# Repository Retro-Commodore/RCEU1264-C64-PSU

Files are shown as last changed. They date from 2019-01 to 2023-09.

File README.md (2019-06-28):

# C64-PSU
A C64/C128/Vic20/Plus4 PSU
This is a full replacement PSU with modern electronics that won't kill your computer when it gets bad.. the original PSU's short input to output, when they break, feeding approx 10v.
While it is possible to use wall warts, this design is created to be easy to diy, somewhat pretty and closer to the old designs with off the shelf items.

Greetz to Trap/Bonzai for being the source of inspiration to create this.

The PSU can be used for the C64 even with i.e. 1541 Ultimate and Vic20, and it's powerful enough to feed the C128 and/or 17xx REU.

All parts can be bought at [tme.eu](https://www.tme.eu/), and the pcb has been designed with parts from there.
A few parts like the DIN connector and fuse socket can be aqcuired from ebay where they're much cheaper.

*If you are a reseller, and use my designs, though the projects are open source, I'd like to ask you to donate a small amount of money, to cancer research for each sold device.*

The Mean Well IRM-20-5 is Short circuit / Overload / Over voltage protected (pdf's from Mean Well are in the documentation folder).

**The trafo is a 230v trafo, so countries that use 115v will need a different trafo.**

If you want to add an on/off switch, the easiest might be a switch on the 230v cable, or a round one, the round one is easiest to make holes to -by drilling-, rather than cutting a square one. But that is entirely up to you :-) .

The gerber files which is the zip file found in [hardware/eagle](https://github.com/Retro-Commodore/C64-PSU/tree/master/Hardware/Eagle Gerber) can be uploaded as is to PCB manufacturing companies like [JLCPCB](http://jlcpcb.com).

The PCB is created with Eagle which has a limiting size of 100x100mm (or is it 100x80mm?). And the PCB is within this size.
The newest version of KiCAD should be able to import the eagle files, in case you prefer this. 

**TODO**
* Add possibility to use PTC (one has to be sourced first), if you read this and know of one already please don't hesitate to add a ticket with the info. You'll providing the community a service :-)

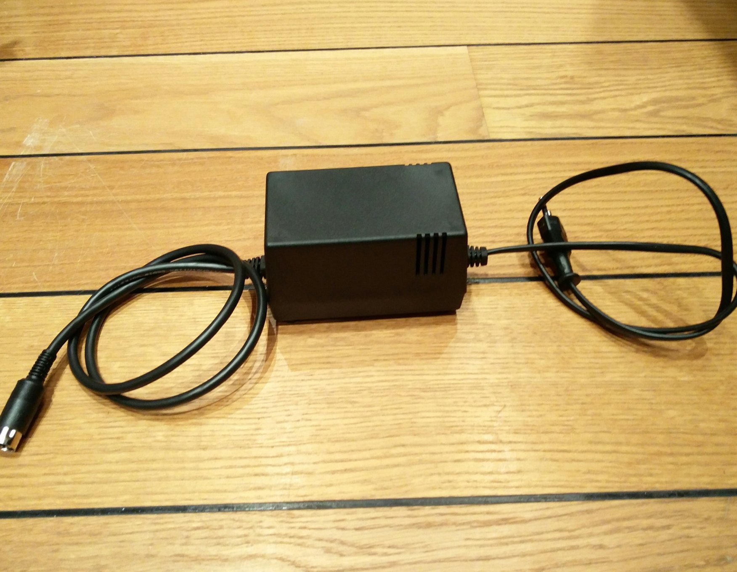
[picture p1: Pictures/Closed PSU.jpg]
PSU


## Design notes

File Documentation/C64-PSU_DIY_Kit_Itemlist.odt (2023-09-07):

Some of the major components needed for the PSU.

9v AC trafo

https://www.tme.eu/en/details/tez10_d_9v/pcb-transformers/breve-tufvassons/tez10d2309v/

4A (who can ever get enough?) with this you can adapt the PSU to work with a C128

5v DC 4A

https://www.tme.eu/en/details/irm-20-5/built-in-power-supplies/mean-well/

Enclosure:

https://www.tme.eu/en/details/z16-abs/power-supplies-enclosures/kradex/z16-abs/

4Wire cable: the last one is preferable

https://www.tme.eu/en/details/cf890.05.04/cables-for-power-chains-unshielded/igus/

https://www.tme.eu/en/details/therm120_4g0.5/multicore-cables-unshielded/helukabel/24004/

The PCB, order at i.e. jlcpcb.com and upload the gerber file (zip file).

Also needed, which can be gotten cheaply from eBay.

Fuse socket

500mA T fuse

7 pin DIN

230v power cable (C7 to Euro)

Optional:

LED

Resistor 330 ohm, might be a good choice but needs calculating depending on color.

A 4A PSU can be created for around £18

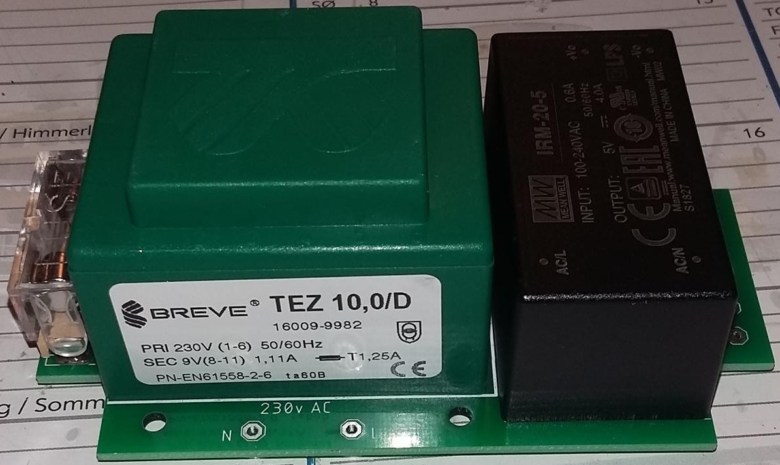
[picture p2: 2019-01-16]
Pictures/pic.jpg

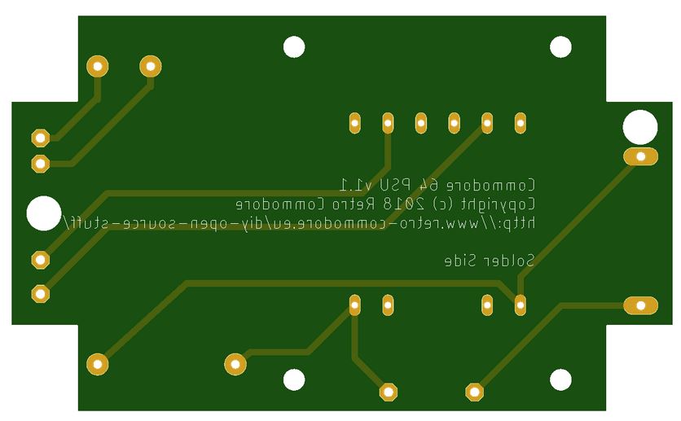
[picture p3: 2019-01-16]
Pictures/bottom.jpg

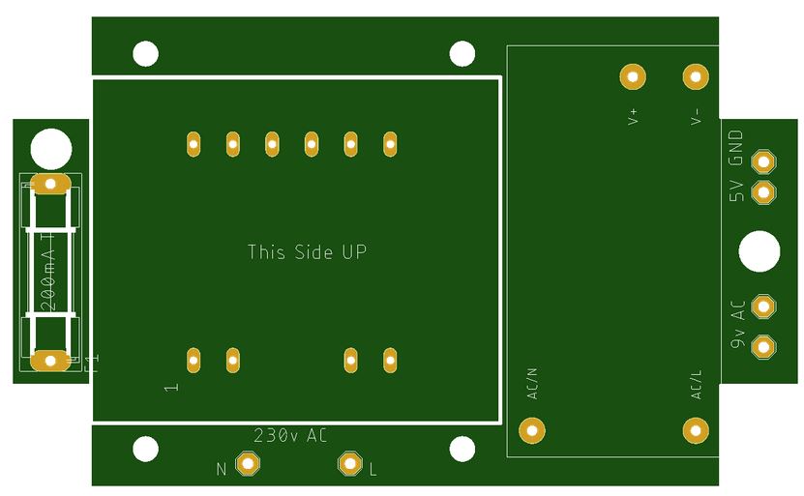
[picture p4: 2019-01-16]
Pictures/top.jpg

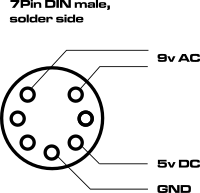
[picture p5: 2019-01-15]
Graphics/DIN.png

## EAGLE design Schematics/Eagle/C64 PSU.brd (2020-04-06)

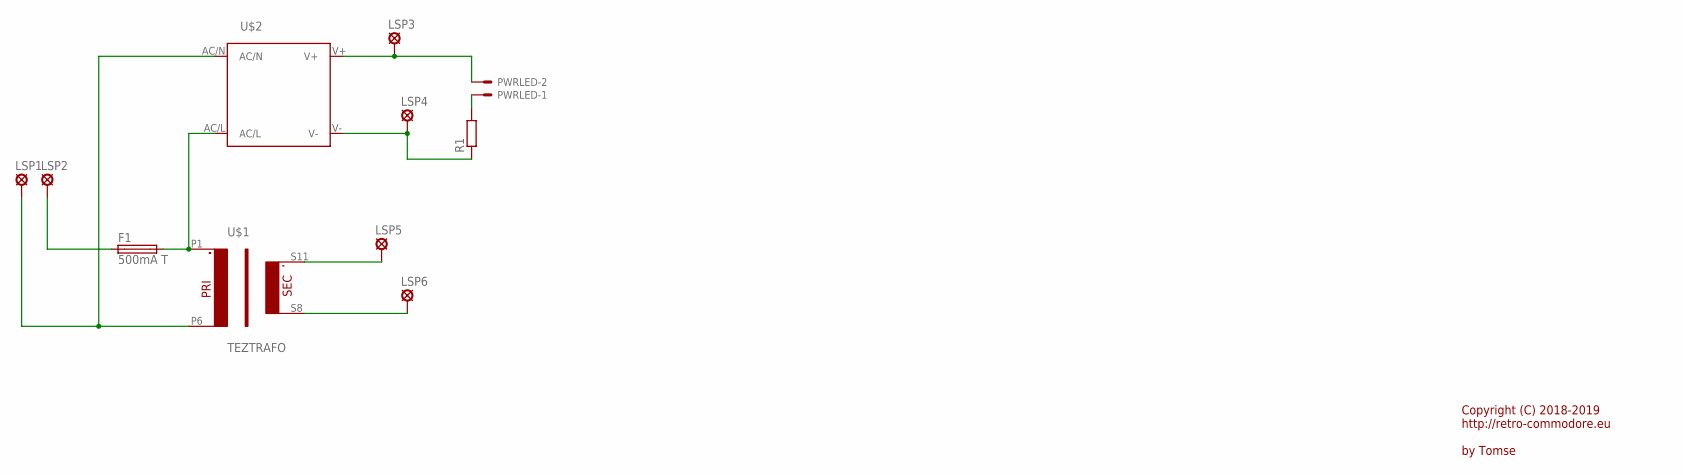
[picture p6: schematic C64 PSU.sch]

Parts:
F1: 500mA T; SH22,5
LSP1, LSP2, LSP3, LSP4, LSP5, LSP6: SE14
PWRLED: 22-23-2021
R1: R-EU_0207/10; 0207/10
U$1: TEZTRAFO; TEZ10/D230/9V
U$2: IRM_15/20IRM_15/20; IRM_15/20

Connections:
unnamed: F1.2, U$1.P1, U$2.AC/L
unnamed: LSP1.MP, U$1.P6, U$2.AC/N
unnamed: F1.1, LSP2.MP
unnamed: LSP6.MP, U$1.S8
unnamed: LSP5.MP, U$1.S11
unnamed: LSP4.MP, R1.1, U$2.V-
unnamed: LSP3.MP, PWRLED.2, U$2.V+
unnamed: PWRLED.1, R1.2

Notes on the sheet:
Copyright (C) 2018-2019 http://retro-commodore.eu by Tomse

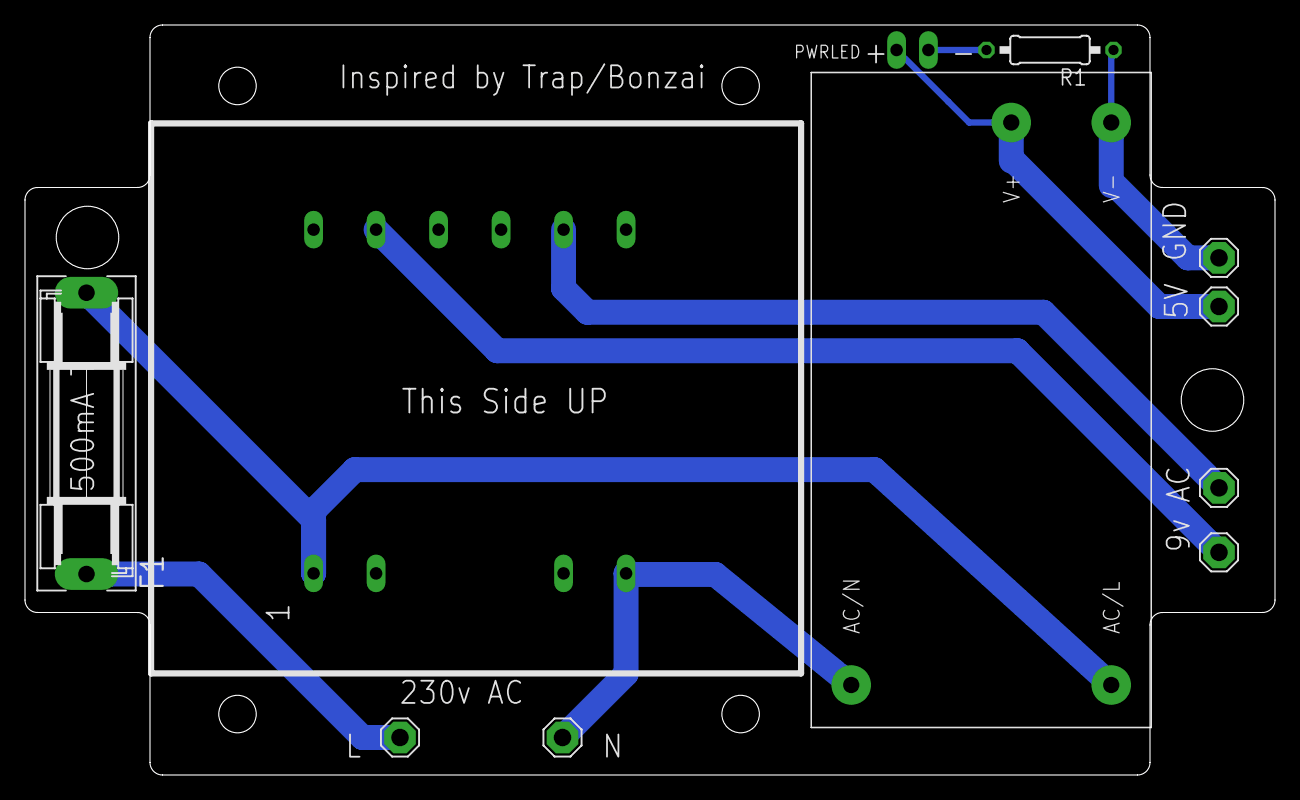
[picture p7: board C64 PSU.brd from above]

Board: 2 copper layers, 100.0 x 60.0 mm, 11 parts (0 on the bottom side), 8 nets.

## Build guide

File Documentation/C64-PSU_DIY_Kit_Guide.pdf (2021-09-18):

# C64 / Vic20 / C128* / plus/4*

# PSU DIY Kit

# from

# http://retro-commodore.eu

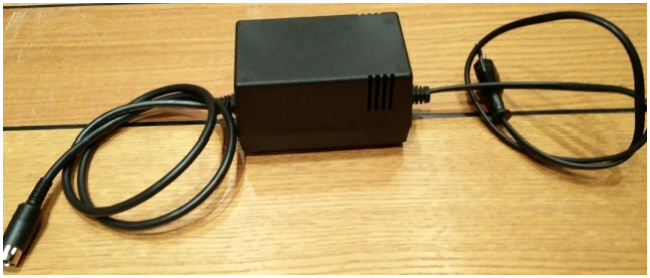
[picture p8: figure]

Table of Contents

Copyright © 2018-2021 http://retro-commodore.eu

### Introduction:

This is the http://retro-commodore.eu version of a C64 PSU.
The project can be found and downloaded for free at https://github.com/Retro-Commodore/ (https://github.com/Retro-Commodore/)
The PSU Works as is with C64 and Vic20, but can be used for C128 and plus/4 as well, with the square DIN connector instead.

### Warning:

Warning! as the psu works with 230v you shouldn’t be soldering this project unless you know what you’re doing. No one but yourself are responsible if the PSU catches fire due to bad/cold soldering joints, so be warned.

### Solder guide:

If you haven’t read the warning, please do so before continuing.

DIN connector

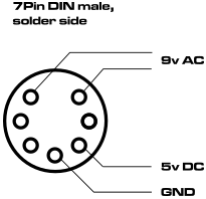
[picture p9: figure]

Copyright © 2018-2021 http://retro-commodore.eu

Print Circuit Board (PCB):
The PCB can mistakenly be solder from both sides, so make sure that you attach the components on top of the PCB hat says ”This Side UP”.

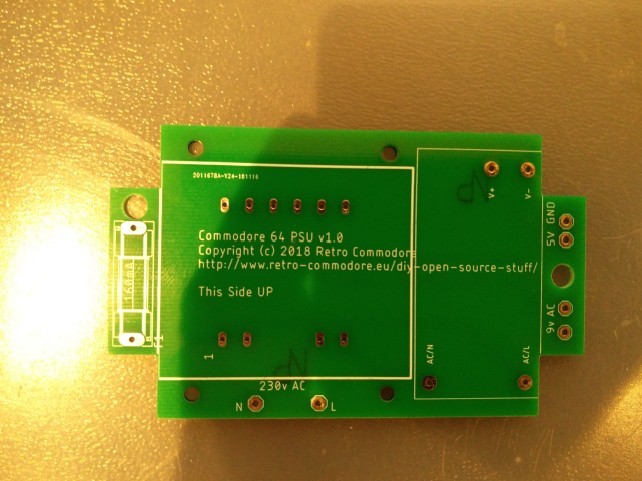
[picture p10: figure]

Copyright © 2018-2021 http://retro-commodore.eu

Trafo:
Insert the trafo on top of the pcb, with the side thats written ”This side up”. The trafo is key coded so you can only insert it one way.
Solder it to the PCB.

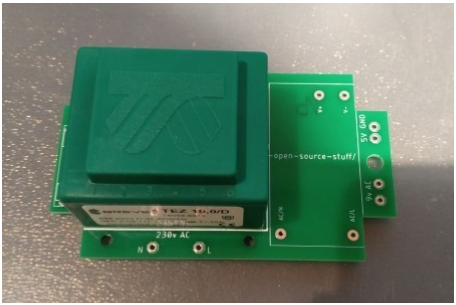
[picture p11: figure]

The trafo generates the 9v AC needed for the SID, if you measure the output you might get around 10v AC, thats fine. The voltage will drop once connected and powered on.

Copyright © 2018-2021 http://retro-commodore.eu

5v supply:
After soldering the trafo, you can now add the 5v psu to the pcb.

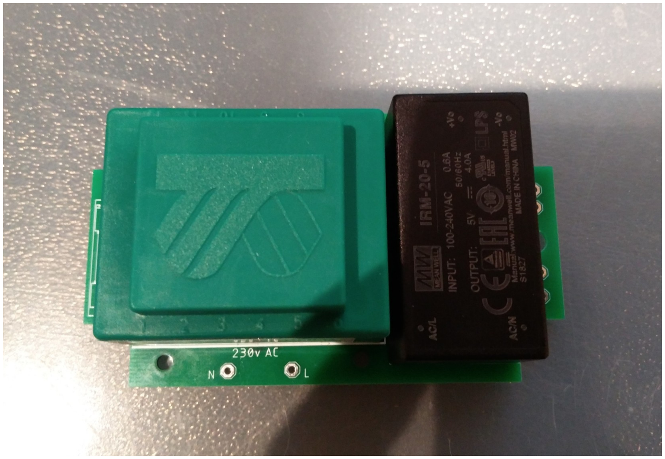
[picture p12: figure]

This model can deliver up to 4A on the 5V, so it’s more than powerful enough to be used with 1541 Ultimate, 17xx Ram expansions, C128 with 17xx Ram expansion etc.

Copyright © 2018-2021 http://retro-commodore.eu

Fuse holder:
Lastly solder the fuse holder. Make sure the fuse isn’t inserted yet as the heat of the solder iron might damage the fuse.

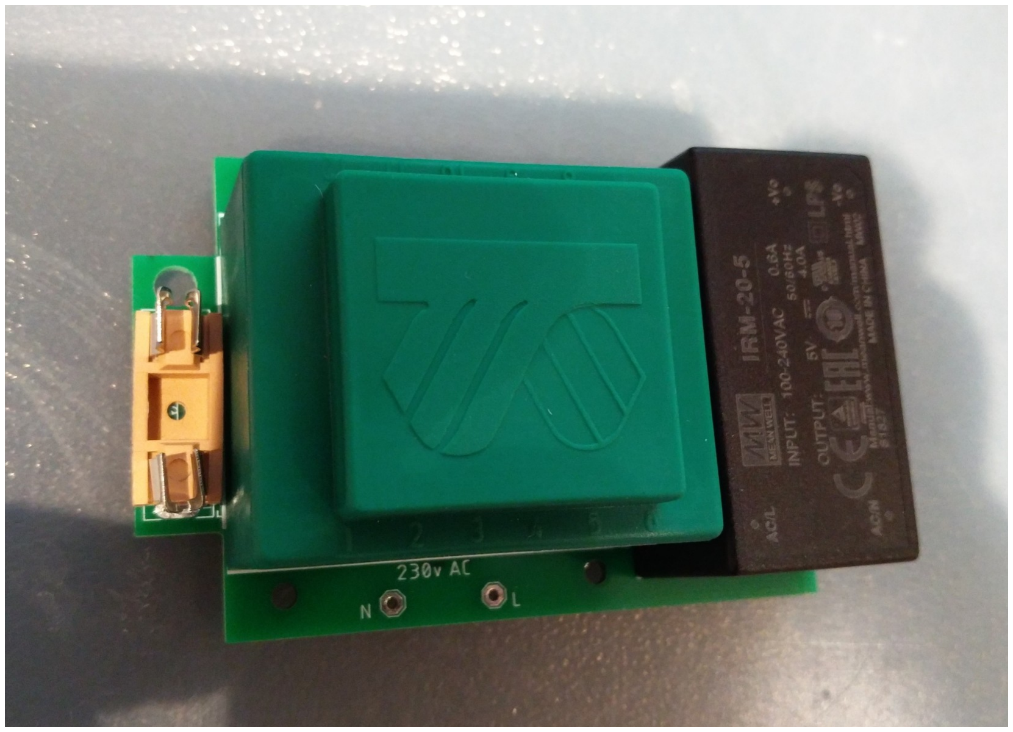
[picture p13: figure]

The fuse is a 500mA T 250V (slow burn) glass fuse. If you’re having problems, or want to have a ”C128” psu, you can upgrade it to a 500mA T 250V.

Copyright © 2018-2021 http://retro-commodore.eu

Wires:
First off, even pros forget this from time to time. Make sure the DIN house is on the cable in the right direction, the same goes with the cable relif’s. Check the directions before soldering the last open end of the cable

This should be self explained, the 230V cable’s red/brown should be soldered to L, and the black/blue should be soldered to N.

Depending on the 4 wire cable you’ve received, just make sure that the AC output next to the 5V psu are connected to the AC solderpins on the DIN connector.
The 5V is connected to the 5V pin on the DIN connector, and of course lastly the GND is connected to GND on the DIN connector.

Put the shield around the DIN connector, make sure it’s mounted correctly. Tighten the metal flippers around the cable and move the house over the shield to close the connector.

Optional LED:
You can solder a resistor of approx 330 ohms and a wire to connect the LED power. The long leg on a LED is +. You might need to do a proper calculation of how large the resistor value should be, by reading the datasheet of the LED. There is 5v across the resistor and LED.

Copyright © 2018-2021 http://retro-commodore.eu

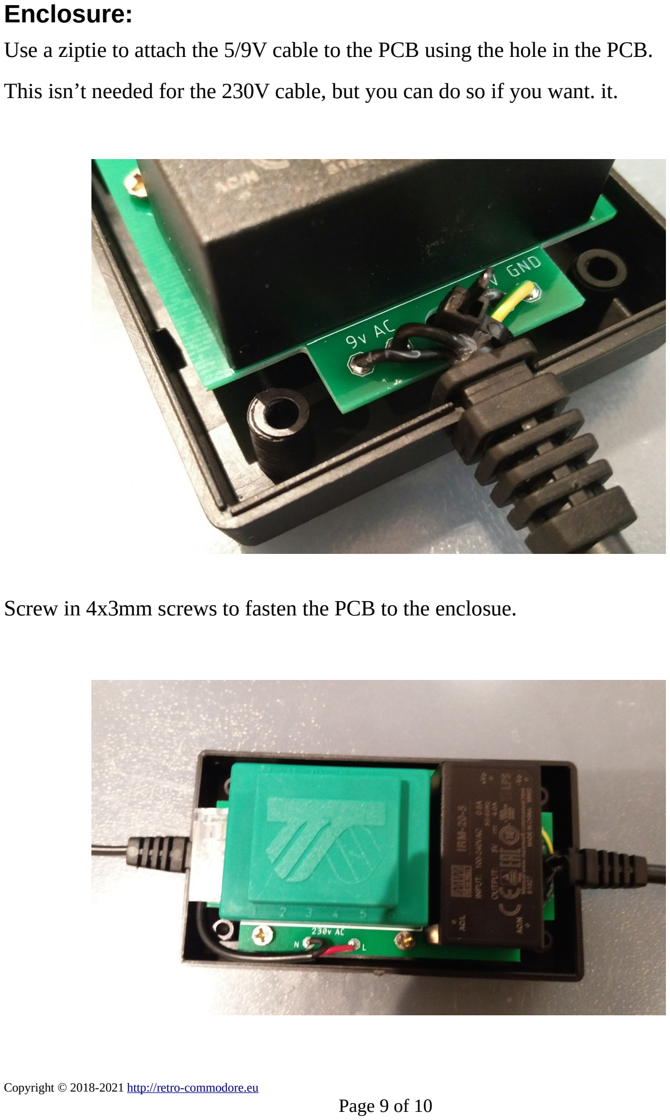
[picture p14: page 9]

Enclosure:
Use a ziptie to attach the 5/9V cable to the PCB using the hole in the PCB. This isn’t needed for the 230V cable, but you can do so if you want. it.

Screw in 4x3mm screws to fasten the PCB to the enclosue.

Copyright © 2018-2021 http://retro-commodore.eu

Put the plastic feet on each screw, close the enclosure, insert each screw into each hole in the bottom of the enclosure and screw in the screws till they are tight.

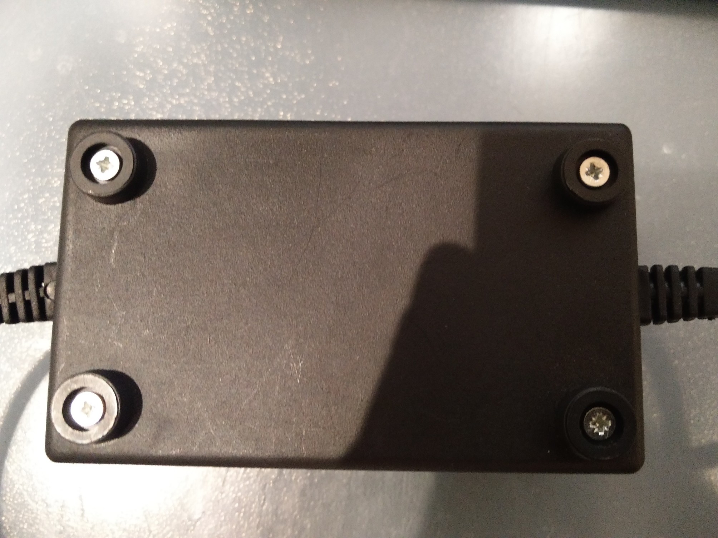
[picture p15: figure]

Enjoy your newly created power supply.

Copyright © 2018-2021 http://retro-commodore.eu

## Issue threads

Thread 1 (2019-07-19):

IRM-10-5 (2A DC Meanwell PSU) is not compatible with PCB

glbyers, 2019-07-19:
Just an FYI to anyone else that is interested in this project. The Meanwell IRM-10-5 PSU as linked in the itemlist is not compatible with the v1.2 board. AC/N and AC/L traces and vias would need adjustment to suit.

Thanks for the project. Simple design for a nice PSU!

tomse, 2019-07-19:
thanks for the info. I've "removed" the IRM-10-5 from the documentation.

I hope you'll find the PSU useful :-)

Closed 2019-07-19.

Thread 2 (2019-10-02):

Texts on bottom layer are not mirrored

fabbrimichele, 2019-10-02:
Hello,

thank you for sharing this project!
I just wanted to report a small issue related to the text in the bottom layer of the circuit board.
I was told by circuit board factory JLCPCB that the text is not mirrored and it should.
See the attached image:
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

tomse, 2019-10-02:
thanks for the report. if you have patience and can wait till the weekend, I can check my v1.4 pcb's
they should be mirrored, the v1.4 boards are produced from jlcpcb and there were no problems.

did you upload the finished gerber files to them?
https://github.com/Retro-Commodore/C64-PSU/blob/master/Hardware/Eagle/Gerber_C64%20PSU_v1.4_2019-06-28.zip

fabbrimichele, 2019-10-02:
Hello tomse,

yes I uploaded the file you mentioned.
I'm wondering if they are mistaking, anyhow I asked them to mirror the text if there is no additional cost.

I'll let you know as soon as I receive the printed circuit board.

Thanks and regards,
Michele

tomse, 2019-10-02:
I just noticed the silkscreen for the fuse says 200mA, but you should get T 500mA instead. the 5v DC module pulls a lot of startup current.
I'll see to fix this for v1.5

fabbrimichele, 2019-10-02:
OK, thanks for the advice!

fabbrimichele, 2019-10-20:
Hello,

I would a question about the fuse, should it be quick blow or time lag?
I found the following ones in the e-commerce site suggested in the documentation:
* quick blow https://www.tme.eu/de/en/details/0217.500hxp/fuses-5x20mm-fast/littelfuse
* time lage: https://www.tme.eu/de/en/details/0218.500hxp/fuses-5x20mm-time-lag/littelfuse

Thanks in advance.

Cheers,
Michele

tomse, 2019-10-20:
time lag / slow blow is prefered here.
cheers

fabbrimichele, 2019-10-21:
Thanks for the answer! I'm going to order the components and build the power supply.

fabbrimichele, 2019-11-02:
Hello,

I finished the PSU. Keeping the cable between the c64 and PSU short 1.10 m,
I managed to have 4.88 volt at U8 on the board.

Thank you very much for your project.

Cheers,
Michele

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

tomse, 2019-11-02:
You're welcome.. as a reference, the original C64 psu gives around 4.6v at the farthest IC on the board, can't remember which IC it is, though lower left corner :-)

fabbrimichele, 2019-11-02:
U8 is on the left side. That means the PSU is great. Thanks again!

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

Closed 2019-11-02.

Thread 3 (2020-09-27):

PCBs

danko79, 2020-09-27:
Hi, sorry if allow myself to open an issue but i don't know how to contact you, i wanted to know if you have some of your pcb's for sale?

tomse, 2020-09-27:
I don't have any pcb's for sale, but you can order 5 by yourself using i.e. jlcpcb.com
create an account, click on quote, and upload the zip file from the Gerbers directory.  5pcs for $2 + shipping, I can't make it cheaper selling just 1 for you.

Closed 2020-09-29.

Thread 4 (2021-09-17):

What fuse is correct?

KeenVox, 2021-09-17:
What fuse is the correct one to use? The item list says 500ma, the building guide 160ma or 250ma.

Thx in advance.

tomse, 2021-09-18:
thank you for the feedback, it has now been corrected in the guide as well.  The correct value is 500mA

Closed 2021-09-18.

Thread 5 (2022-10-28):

C64 with 6580 Sid

KeenVox, 2022-10-28:
Does it work with 6580 Sid motherboards? Afak those need 12V AC?

KeenVox, 2022-10-28:
Didn't realisethe 12V DC are converted from the 9V AC.

Closed 2022-10-28.

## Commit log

2019-01-15 Initial Relase
    [C64 PSU.brd, C64 PSU.sch]
2019-01-15 Fixed solder pads for trafo
    [C64 PSU.brd, C64 PSU.sch]
2019-01-16 Small updates based on ycombinator comments
    [C64 PSU.brd]
2019-06-26 added power led connectors
    [C64 PSU.brd, C64 PSU.sch]
2019-06-28 Improved traces
    [C64 PSU.brd, C64 PSU.sch]
2019-06-28 Updated Gerber with v1.4
2019-06-28 cosmetic changes
    [C64 PSU.brd]
2019-06-28 Added documentation for LED
2019-10-14 Fixed text
    [C64 PSU.brd]
2020-04-06 Fixing dirnaming
    [C64 PSU.brd, C64 PSU.sch]
2021-09-18 Fixed correct fuse value
2023-09-07 Fixed url to enclosure and cleanup

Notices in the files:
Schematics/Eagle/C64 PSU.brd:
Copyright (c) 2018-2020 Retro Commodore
